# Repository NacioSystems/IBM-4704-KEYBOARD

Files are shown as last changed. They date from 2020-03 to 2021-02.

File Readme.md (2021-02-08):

# CONVERSOR IBM 4704 A USB:

## de NacioSystems:

Versión 1.0
Fecha 28/2/2020

Con este proyecto se explica la construcción de un interfaz para el teclado español 4704 de IBM de 62 teclas, para su utilización por USB en cualquier otro ordenador. 

---

### Introducción:

Paseado por el Rastro, en 1985, encontré un puesto que tenia varios teclados y terminales en venta. Tenía la pinta de que en una sucursal de banco habían cambiado de sistema y se habían deshecho de pantallas, terminales, impresoras y teclados. Había varios teclados, creo recordar que unos completos con caja, teclados de funciones y varios expandidos. 

Me llamó la atención, era la época de los *Conmmodore 64* y los *Spectrum*, esos teclados no estaban al alcance de cualquiera. En el Rastro nada es de fiar y no quería gastar mucho. Pregunté el precio y había uno económico por unas 100 pesetas. Se trataba de un teclado de terminal IBM 4704, que tenía la apariencia de estar estropeado, pues este en concreto era más barato y no disponía de caja externa.

Me gustó mucho su tacto, su sonido y decidí comprarlo. El teclado lo tuve de adorno en mi época de estudiante, lo guardé y muchos años después supe que estaba considerado uno de los mejores teclados, el *IMB Modelo F*, que por ser capacitivo superaba en prestaciones al más conocido Model M, tambien de IBM.

En 2020 decidí ponerlo en marcha y encontré mucha información en Internet. En concreto el proyecto de *[Soarer][1]*, quien destripó el hardware y el software del microprocesador Intel 8048, lo que a su vez permitió el desarrollo de otros proyectos de reconversión de este teclado en modelo USB, como es el caso del proyecto *[TMK][2]*.

Kishsaver Pruebas conexión

Este teclado es una matriz de 62 teclas, 8x8, en la que uno de los puntos de la matriz no es una tecla, el 63, es un código fijo que identifica el teclado, en mi caso 0xA3h. Para la lectura de la matriz se utiliza un controlador Intel 8048, aunque el teclado que yo tengo está marcado con un código diferente (8315), básicamente es un 8048, que se encarga de alimentar sucesivamenta cada una de las 8 filas, seleccionar cada una de las 8 columnas, mientras lee el valor 1 / 0 del pin 1, denominado TO. Interiormente el 8048 dispone de un microprocesador Intel de 8 bits, memoria RAM de 64 bytes y una ROM de 1kB, así como 3 puertos configurables de entrada salida tambien de 8 bits. La seleccion de las columnas es a través de un chip específico IBM (sensor capacitivo customizado IBM 9314) con entrada decimal (tres bits 0-7 que seleccionan la salida) y una salida por cada columna (8 salidas). Las entradas y salidas de Data, Clock y Buzzer se realizan a traves de puertas lógicas adicionales, que evitan cargar las salidas del 8048. Estas salidas están puestas en Pull-Up.

En concreto, para el modelo de 62 teclas, que los expertos llaman *Kishsaver*, realmente solo utiliza un puerto de 8 bits para el Strobe, la selección de filas, y mitad de otro puerto de 8 bits (bits 0, 1 y 2) para la selección de columnas. Un cuarto bit lo utiliza para la carga de los condensadores a través del IBM 9314 y un bit adicional para la lectura del Strobe de la tecla (que no existe) del código de teclado (ver imagen 8048).

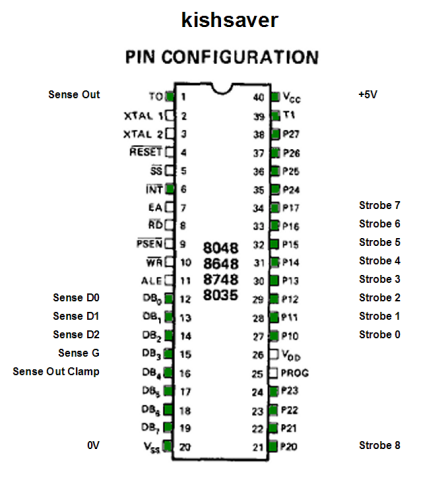
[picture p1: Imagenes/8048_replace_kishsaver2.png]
Intel8048 Intel 8048


La construcción es impresionante. Lleva dos planchas metálicas en las que encajan, en modo sandwich la placa de circuito impreso PCB y las teclas. La placa PCB está totalmente cubierta por una capa aislante por las dos caras, el soporte de la PCB hace de dieléctrico. Los contactos no son realmente contactos, son superficies que hacen de condensadores. El conjunto es sólido, el que yo tengo pesa 1.6Kg, pero he visto que el original con la caja de fundición pesa 2.8Kg. !Impresionante!

El teclado que yo tengo es un modelo de teclado español, con letra Ñ y otras teclas cambiadas de sitio respecto del teclado estándar, por lo menos la versión americana que documentó Soarer. A este teclado le encontré dos *Buckling springs*, los martillos de IBM rotos. Con estas características no resutla fácil la aplicación directa de un software estandar tipo *[Soarer][1]*, para aprovechar todas las capacidades de este teclado. 

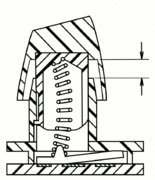
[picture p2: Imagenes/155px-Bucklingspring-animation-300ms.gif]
BucklingSpring Sistema IBM Buckling Spring


Es posible conseguir hardware adicional para reemplazar la placa controladora original por una más moderna, con puerto USB, pero los precios no son precisamente económicos. Hablamos de unos 41$ más gastos de envío (Ver proyecto TMK). 

Este modelo resultó tan bueno, que a través de micromecenazgo se creó un proyecto que diseñó, fabricó y vende este tipo de teclados, las piezas son iguales a las originales, y se respetó la calidad de los materiales. Esta calidad y la falta de economías de escala no permite que sea barato, los precios, para cualquiera de estos teclados andan por los 350$ más gastos de envío. Venden también piezas sueltas, cajas, martillos *buckling spring*, cápsulas de teclas, controladoras. Ver tienda en *[Model F Keyboards][9]*. Recomiendo ver el análisis en Youtube de *[Chyrosran22][10]*. En cualquier caso, los precios en el mercado de segunda mano para los Modelos F originales, superan estos precios.

Tomé la decisión de poner mi teclado a funcionar y me propuse buscar alternativas utilizando la información que *[Soarer][1]* ha hecho pública. La primera alternativa fue conectar un adaptador entre el bus del teclado y PC, con salida USB, basada en *Arduino Nano*. Si esto no funcionaba, en segundo lugar tenía previston reemplazar el controlador Intel 8048, instalando un zócalo de 40 pines, al igual que hizo *[Soarer][1]*, y reprogramando todo desde cero. Esta segunda alternativa era la que ofrecía más probabilidades desde mi punto de vista, ya que tenía el presentimiento de que el Intel 8048 no funcionaba.

Más tarde encontré, en el Github de *[iflowfor8hours][3]*, como hacer un conversor USB utilizando una placa Pro Micro, una placa similar a la placa Tennsy, la que utiliza Soarer, aunque con una configuración más limitada. Ambas placas vienen a ser un Arduino Leonardo reformado, en miniatura, con un microcontrolador _*ATmega32U4*_. Este controlador lleva incorporado un puerto USB nativo, lo que facilita enormemente la simulación de dispositivos *HID* en el ordenador.

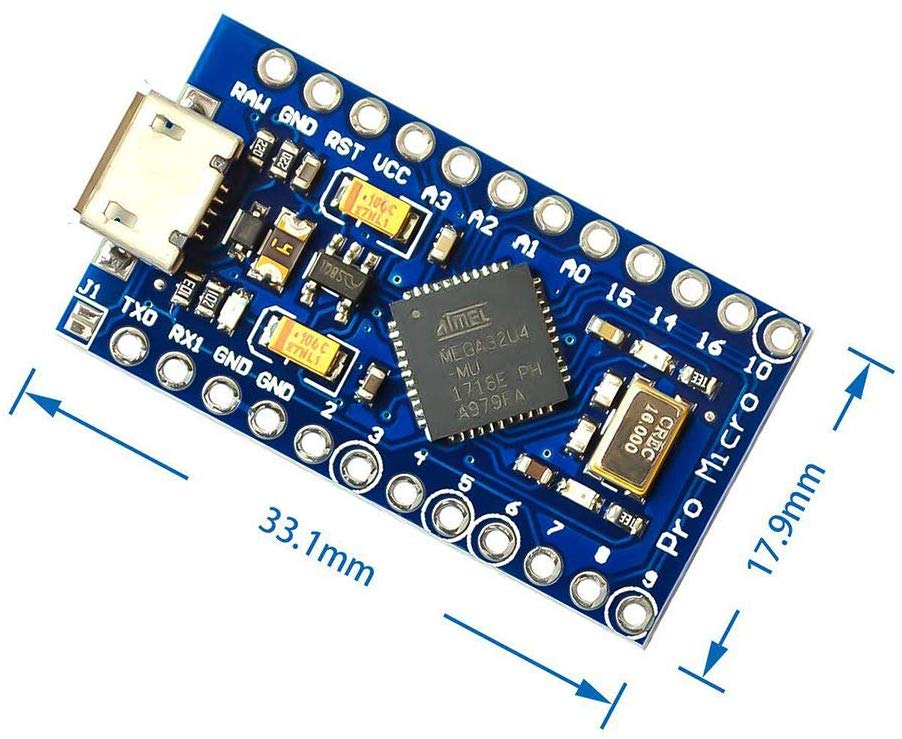
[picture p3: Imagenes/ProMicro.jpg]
ProMicro Pro Micro


El resultado no es inmediato, siguiendo las instrucciones de Soarer conseguí, despues de pelearme un poco con la información, salir del modo comando en el que se inicia el teclado y leer las teclas. Esto me permitió confirmar que el procesador IBM 8048 y el resto de la placa funcionan perfectamente despues de más de 35 años sin conectar.

Previamente a todo esto, desmonté el teclado, pues la suciedad acumulada en 35 años era considerable. Durante varios días estuve limpiando la placa, las cubiertas de acero, los soportes de las teclas y las teclas. Lo que más trabajo me dió fueron los soportes de las teclas ya que la cubierta de espuma que cubría las teclas, entre estas y la placa de acero superior, estaba desintegrada y pegada como con cola a los soportes de las teclas.

Una de las complicacines más difíciles fue el envío de comandos desde PC al teclado. Algunos comandos si los recibía sin problema, por ejemplo el comando RESET o SOFT_RESET, pero el resto de comandos como poner los *Break Codes* o los *Repit Codes* fué más complicado, parecía que los aceptaba y sin embarno no los ejecutaba. El problema estaba en que el teclado funciona siempre como maestro, manejando el reloj CLK, tanto en la lectura de códigos de escaneo como cuando se le envían datos de comandos, y yo intentaba enviarle los comandos controlando el reloj desde el PC. Una vez descubierto esto ya me puse a configurar un programa para que el IBM 4704 tenga un uso más funcional posible como teclado en español. Y funciona tan bien que es el teclado que utilizo:

Por cierto el teclado original tiene un beeper, un zumbador en base a electroimán, que suena en cada tecla pulsada. Creerme, el sonido de los martillos al pulsar la teclas hace innecesario dicho zumbador.

Una curiosidad interesante es que haciendo pruebas he descubierto que, con el teclado desarmado, sin teclas, con la placa base conectada, la simple pulsación con los dedos sobre las placas de los condensadores detecta cada una de las teclas. Es decir, los dedos pueden hacer de martillos capacitivos. Esto produce algunos errores de lectura de los Scan Codes, pero uno termina encontrando la forma de teclear sin teclas. Viendo esto voy a probar con otros tipos de materiales conductivos para ver si puedo reemplazar los dos martillos rotos.

### Materiales:
* Teclado IBM 4704 62 teclas, Kishsaver, modelo F
* Sparkfun Pro Micro

### Programa:

El programa está realizado con el IDE Arduino, para su programación directa a través de cable USB. En la carpeta software se puede ver el programa comentado. El pineado está explicado en los comentarios, sólo es necesario montar el cableado para la comunicación con el IMB 4704 y el puerto USB. La conexión con el PC abre un puerto HID Keyboard standar, para el envío de la información tecleada, pero por otra parte abre simultáneamente un puerto COM, en el que permite visualizar los códigos de escaneo del telcado, los códigos de conversión de teclas y los comandos enviados.

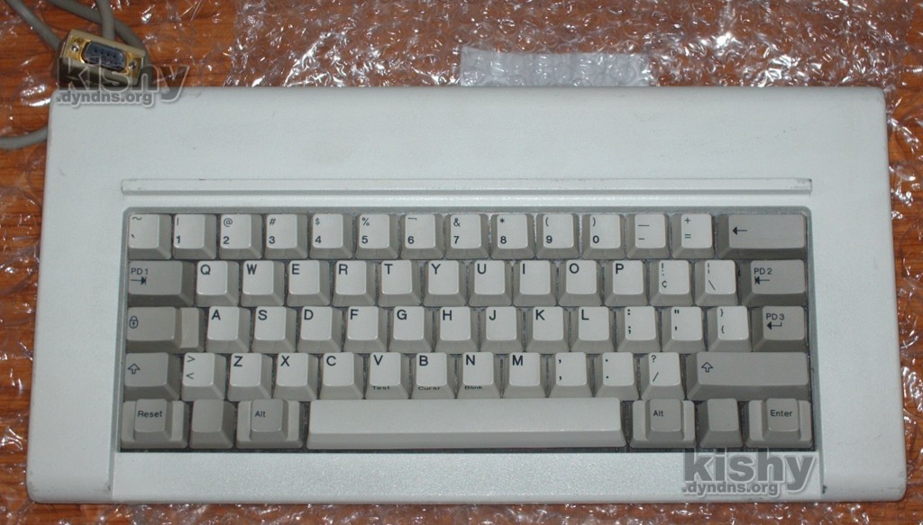
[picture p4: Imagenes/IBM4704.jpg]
IBM4704 IBM 4704 Kishsaver


### Construcción:

La construcción es en base es la plataforma **_Sparkfun Pro Micro_**, a la que se le han soldado conectores *duppond* hembra en los pines Vcc, GND, A3 y A4, los primeros para la alimentación de la placa con el procesador Intel 8048, los segundos para las fuciones de comunicación de IBM, CLK y DATA. 

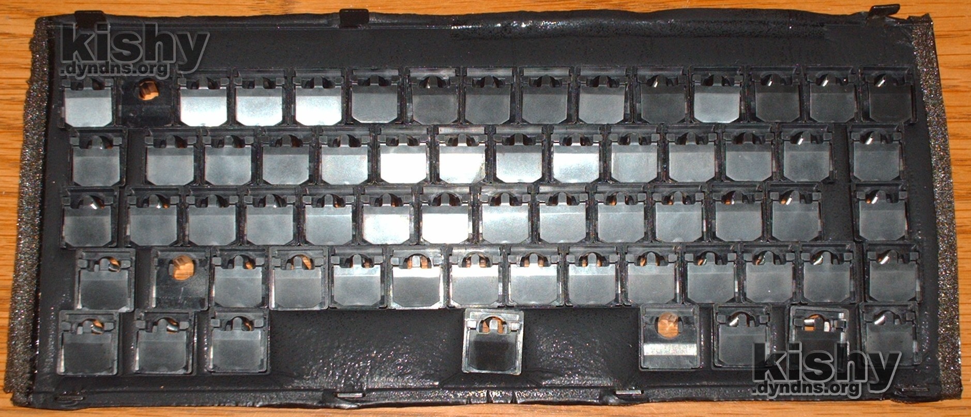
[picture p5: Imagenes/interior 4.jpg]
Martillos Interior, martillos


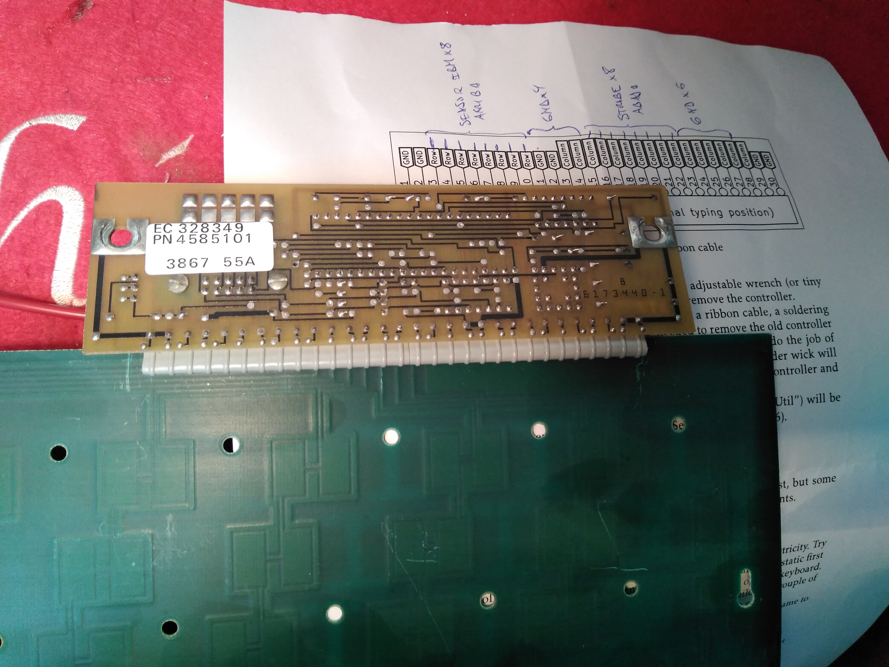
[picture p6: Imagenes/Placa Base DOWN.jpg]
Inferior Vista placa inferior


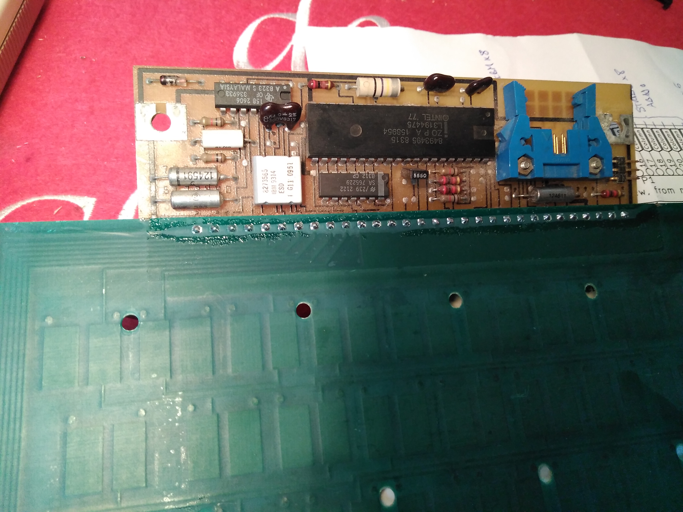
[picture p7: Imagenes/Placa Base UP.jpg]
Superior Vista placa superior


Por otra parte se diseñó una caja funcional, similar a la original de IBM, impresa en PLA, con una impresora 3D.

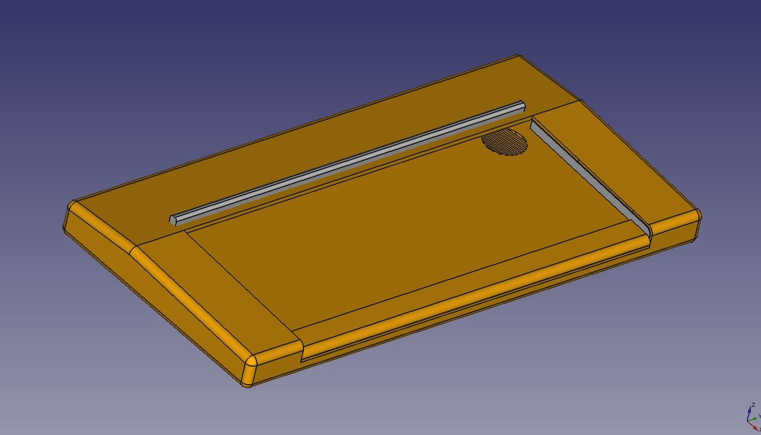
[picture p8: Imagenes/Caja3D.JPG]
Caja3D Modelo caja 3D


### Piezas impresas:

En la carpeta de piezas impresas, están los modelos Stl de la caja para el Kishsaver, imitando la caja original, modelo sacado a partir de la fotos ofrecidas por *[Kishy.ca][8]*.

Está tamibién el archivo FreeCad por si alguien quiere modificar dicha caja.

La impresora 3D que yo tengo tiene una superficie muy limitada, 200x200mm, lo que no me permite construir de una vez las dos partes, inferior y superior. Para poder imprimirlo, corté las piezas superior e inferior en dos partes dada una, derecha e izquierda, con unas dimensiones aceptables para el tamaño de la impresora. El material que utilicé es PLA de color dorado. 

Las mitades izquierda y derecha las pequé con cola y las uní con las levas inferior y superior para darle un refuerzo. La unión es con tornillos de métrica M3. Hay unas tuercas 4xM3 también embibidas en la parte superior, para sujetar con fuerza los tornillos. En la parte inferior tuve que meter un refuerzo, yo lo pegué con cola pero dejé espacio para tornillos, para hacerlo más rígido.

### Referencias:

* *[IBM 4700 Kishy.ca][5]*

* *[IBM 4704 to USB keyboard converter][6]*

* *[XT / AT / PS2 / Terminal to USB Converter with NKRO][7]*

* *[Sparkfun Pro Micro][4]*

### Autor:
**Ignacio Otero**

### Agradecimientos:

Muy agradecido tanto a *[Soarer][1]*, como *[iflowfor8hours][3]*, así como a *[http://kishy.ca][8]*, quienes me permitieron acceder a información esencial para conocer el funcionamiento de este teclado.

### Licencia:
Todos estos productos están liberados mediante Creative Commons Attribution-ShareAlike 4.0 International License.

[1]:https://deskthority.net/viewtopic.php?f=7&t=2510&start=

[2]:https://github.com/tmk/tmk_keyboard/tree/master/converter/ibm4704_usb

[3]:https://github.com/iflowfor8hours/6112884-pro-micro-controller

[4]:https://www.sparkfun.com/products/12640

[5]:http://kishy.ca/?p=648

[6]:https://github.com/tmk/tmk_keyboard/tree/master/converter/ibm4704_usb

[7]:https://geekhack.org/index.php?topic=17458.0

[8]:http://kishy.ca/?p=894

[9]:https://www.modelfkeyboards.com/

[10]:https://www.youtube.com/watch?v=nlbbBvS8wVY

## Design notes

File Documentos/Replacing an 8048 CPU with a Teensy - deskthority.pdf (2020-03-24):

Post Reply | First unread post • 15 posts • Page 1 of 1

# Replacing an 8048 CPU with a Teensy

Register | Login

mechanical keyboard authority

Soarer

07 Oct 2012, 04:58

My goal for this project is to get a DisplayWriter keyboard (beam spring) and the kishsaver (a Model F) converted to USB and usable. They don't have protocols that are usefully convertible, because they don't send release codes (or rather, they only send them for one or two keys).

Fully replacing the controller is an option - dfj has done so with a 122-key F, and it works well. But I fancied taking a different route, preferring to drive the IBM capacitive sensing chip by replacing the CPU. This means desoldering the original CPU, which naturally carries some risk of damage, but I've been lucky so far!

Some of the information here could of course be useful for replacing the 8048 in other, non-IBM, keyboards. The 8048 pins that might be used to scan a switch matrix are marked in green on this pinout:

Replacing an 8048 CPU with a Teensy - deskthority | https://deskthority.net/viewtopic.php?f=7&t=4019&start=
1 de 12 | 10/02/2020 10:03

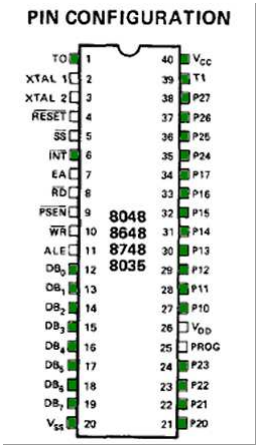
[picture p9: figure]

8048_replace.png (56.45 KiB) Viewed 3290 times
They are never all used just for reading the matrix. Some will be driving the external interface, and some may be driving LEDs. So a Teensy should have enough pins for any case, just! OTOH, something like a Teensy++ would make it easier to make a logical mapping between the 8048's three 8-bit ports, since the Teensy++ has four full ports (and/or might make physically mounting it in place easier, but more of that later).

Of the IBM controllers, there's a distinct similarity in pin use between the PC/XT and DisplayWriter (although of course there are big differences in pin use for the external interface):

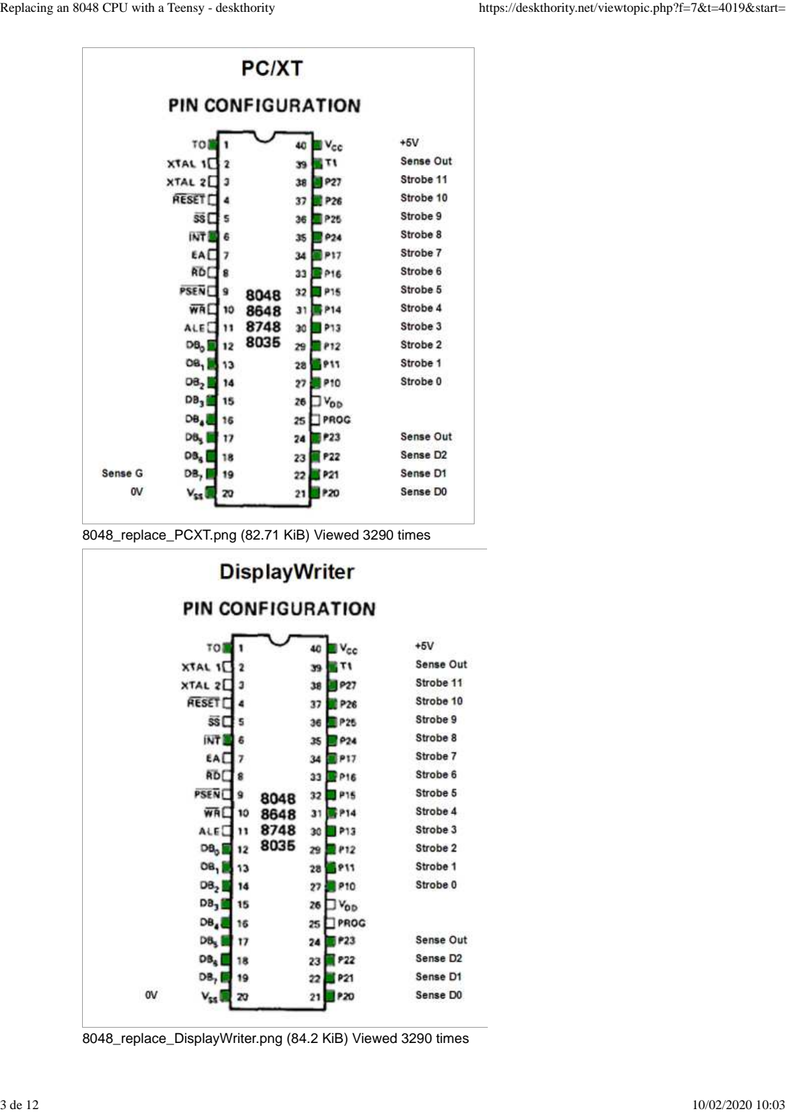
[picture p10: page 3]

8048_replace_PCXT.png (82.71 KiB) Viewed 3290 times

8048_replace_DisplayWriter.png (84.2 KiB) Viewed 3290 times

The AT uses a multiplexer for driving the strobe lines, so it doesn't use many pins at all. This same arrangement is also used in at least some of the 122-key terminal controllers:

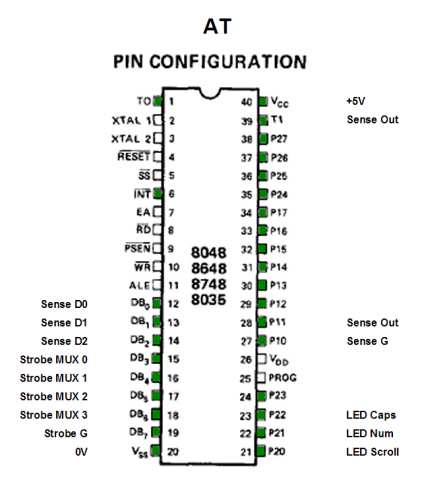
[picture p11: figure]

8048_replace_AT.png (78.69 KiB) Viewed 3290 times
And finally the kishsaver simply doesn't have many keys, so has fewer strobe lines:

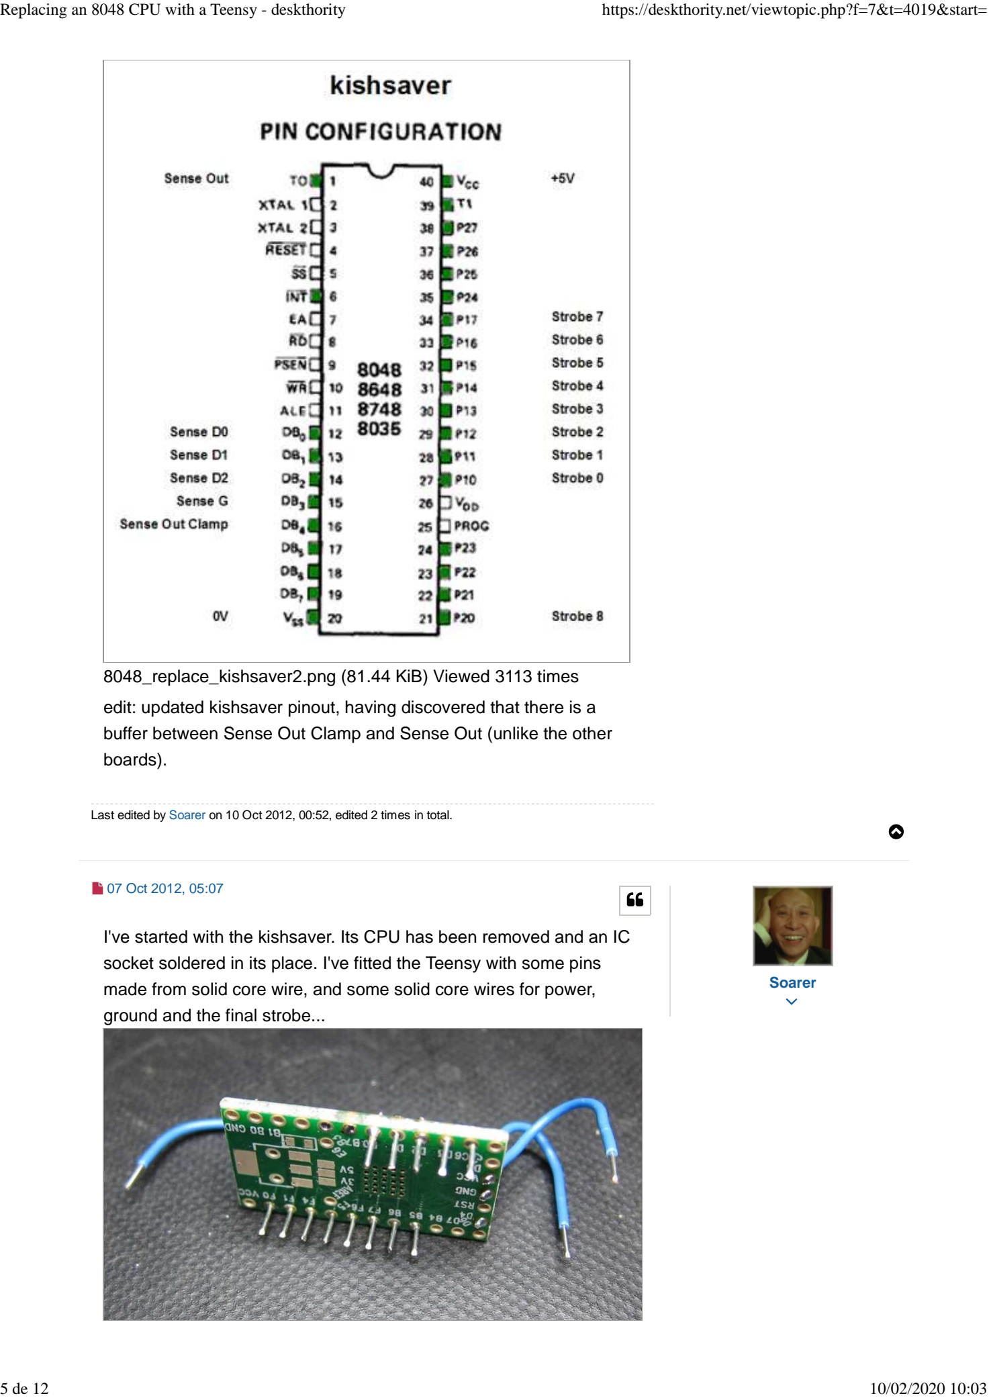
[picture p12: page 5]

8048_replace_kishsaver2.png (81.44 KiB) Viewed 3113 times edit: updated kishsaver pinout, having discovered that there is a buffer between Sense Out Clamp and Sense Out (unlike the other boards).

Last edited by Soarer on 10 Oct 2012, 00:52, edited 2 times in total.

Soarer

07 Oct 2012, 05:07

I've started with the kishsaver. Its CPU has been removed and an IC socket soldered in its place. I've fitted the Teensy with some pins made from solid core wire, and some solid core wires for power, ground and the final strobe...

kishsaver_teensy_pins.jpg (218.85 KiB) Viewed 3286 times

kishsaver_teensy_wires.jpg (263.67 KiB) Viewed 3286 times edit: updated this pic now that I've added a fourth wire to connect to the real Sense Out...

kishsaver_teensy2.jpg (258.07 KiB) Viewed 3108 times
Of course, I'll trim the wires a bit more when I'm happy with it!

I picked that position for the Teensy because it covers most of the used 8048 pins, and specifically it lines up PD0 to PD2 with Sense D0 to D2 - those three want to be changed together, so they at least need to be on the same Teensy port. The rest of connections will be read/written individually, so it doesn't matter if they're on different ports.

Last edited by Soarer on 10 Oct 2012, 00:48, edited 1 time in total.

07 Oct 2012, 07:02

To sniff the logic of the capacitive sensing chip, the AT is good

Soarer because of the multiplexer - less probes to attach!

A full scan of the entire matrix looks like this:

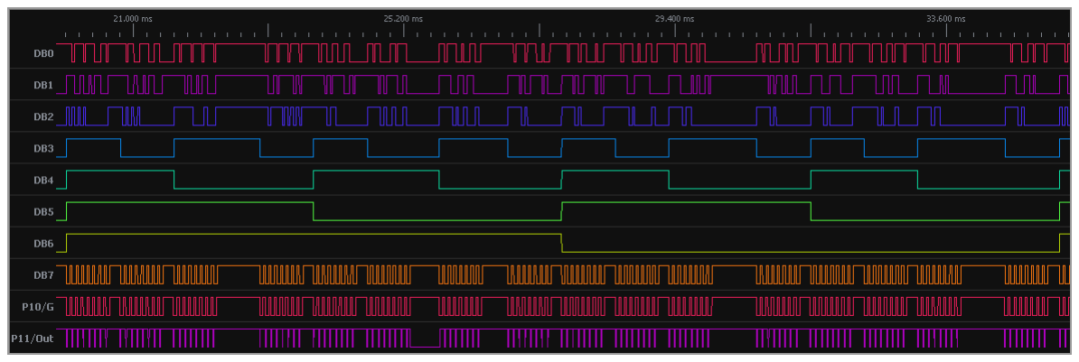
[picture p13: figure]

logic-sniff-at-f.png (6.17 KiB) Viewed 3272 times
Scanning the keys on a single column (or row, if you prefer), like this:

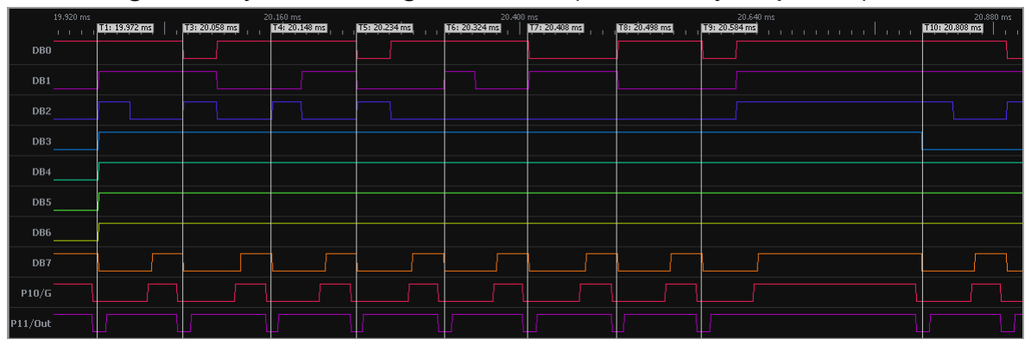
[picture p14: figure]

logic-sniff-at-f-2.png (6.83 KiB) Viewed 3272 times
Note that the Sense D0 to D2 lines (DB0 to DB2) serve a dual purpose - first, they select which key to read, and second, they set a sensitivity level (for which there is a table in the ROM).

When a key is pressed, the sense chip output (Out) goes low, when gated by the G line going high. The fifth key read in this scan is pressed:

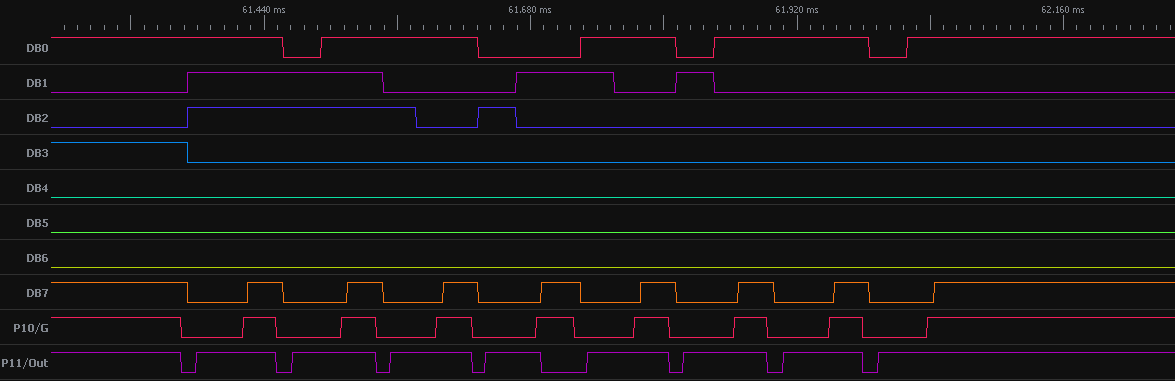
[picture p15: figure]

logic-sniff-at-f-f1-down.png (4.69 KiB) Viewed 3272 times
This subroutine from the AT's firmware reads a column of 8 keys:

CODE: SELECT ALL

X0251: clr | c | ; 0251 - 97 | .
mov | r0,#8 | ; 0252 - b8 08 8.
mov | r6,#0 | ; 0254 - be 00 >.
mov | a,r2 | ; 0256 - fa | z
dec | a | ; 0257 - 07 | .
anl | a,#0f8h | ; 0258 - 53 f8 Sx
mov | r7,a | ; 025a - af | /
X025b: dec | r2 | ; 025b - ca | J
anl | p1,#0fch | ; 025c - 99 fc .|
mov | a,r2 | ; 025e - fa | z
outl | bus,a | ; 025f - 02 | .
orl | p1,#2 | ; 0260 - 89 02 ..

rrc | a | ; 0262 - 67 | g
movp3 | a,@a | ; 0263 - e3 | c
jc | X0267 | ; 0264 - f6 67 vg
swap | a | ; 0266 - 47 | G
X0267: anl | a,#7 | ; 0267 - 53 07 S.
orl | a,r7 | ; 0269 - 4f | O
outl | bus,a | ; 026a - 02 | .
clr | c | ; 026b - 97 | .
nop | | ; 026c - 00 | .
nop | | ; 026d - 00 | .
nop | | ; 026e - 00 | .
orl | p1,#1 | ; 026f - 89 01 ..
orl | bus,#80h | ; 0271 - 88 80 ..

bhtooefr

07 Oct 2012, 12:40

Also, this method (but with different pinouts) will be useful for getting other beam springs going. (I'm looking over kbdbabel's 5251 schematic right now, at the AMI chip that I believe is the microcontroller. Unfortunately, the pinout doesn't match any kind of AMI microcontroller that I can find...)

Soarer

07 Oct 2012, 14:04

True... the CPU details aren't really as relevant as the peripherals around it, although it helps to cheat by looking at the code!

That 5251 uses the 4-channel version of the capsense chip - I would guess it's mostly driven in a similar fashion, but the 8-channel version doesn't have the U1 connection, so no idea what that's doing.

This thread could do with a more appropriate title. At first I was thinking of wiring a Teensy++ up to a DIL plug, so I could use it to replace the 8048 in any controller, but then I decided to just focus on one board first and make the simpler drop-in.

Soarer

07 Oct 2012, 14:24

For local reference, here are symbols for the capacitive sensing chips that akurz has used in the kbdbabel schematics.

The 4-channel version (5251 schematic):

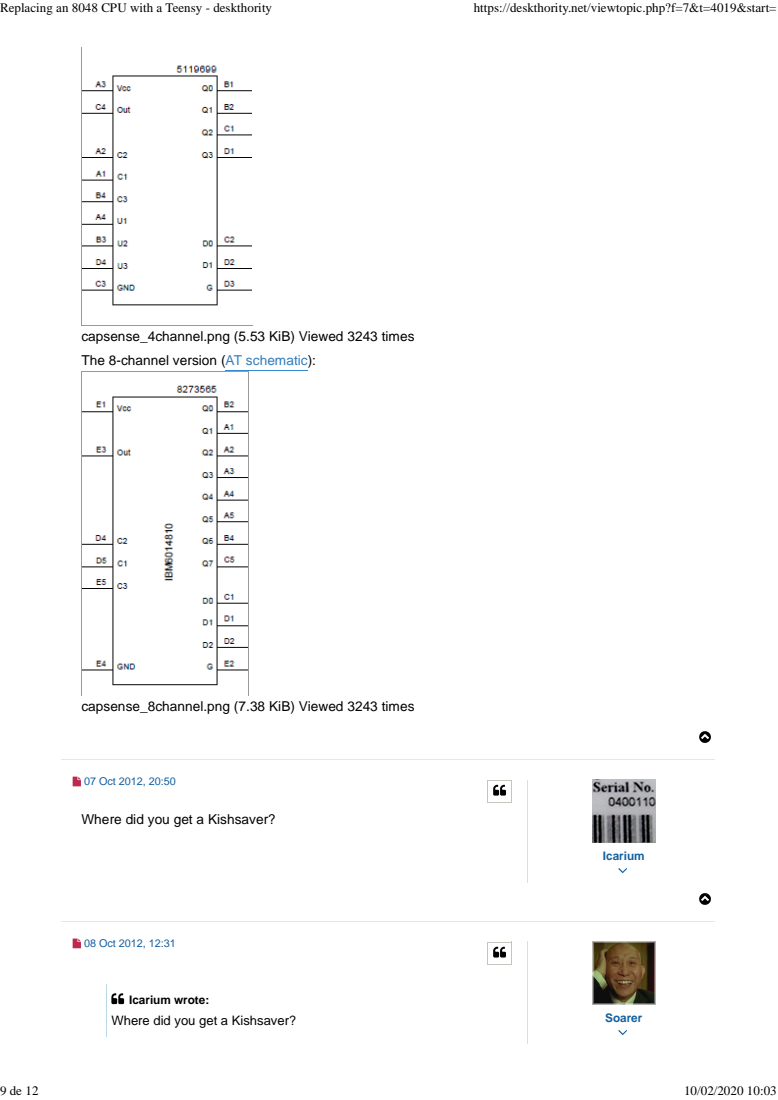
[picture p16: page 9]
Icarium; 07 Oct 2012, 20:50; Soarer; 08 Oct 2012, 12:31

capsense_4channel.png (5.53 KiB) Viewed 3243 times
The 8-channel version (AT schematic):

capsense_8channel.png (7.38 KiB) Viewed 3243 times

Where did you get a Kishsaver?

Icarium wrote:

Via another member. The source has dried up.

REVENGE 09 Oct 2012, 08:58

Interesting! Look forward to seeing what you manage to come up
with!

Soarer

10 Oct 2012, 01:14

Well I managed to get the matrix scan code basically working last night, but it will take a lot of trial and error to get it fully reliable!

I've updated a couple of the pics in the earlier posts because the kishsaver has a buffer connected to the pin it uses to clamp the Sense Out line low. None of the other controllers have a buffer there! Sense Out is the output from the capacitive sensing chip, and is normally connected to two pins on the CPU - one for reading it, and one for clamping it to ground. From the timing, this clamping could be an acknowledge back to the sensing chip - it appears to clear the previous output back to the unpressed state (high).

dorkvader

12 Oct 2012, 01:09

This is some very good and in-depth work! Would it be possible to adapt this project with some other components (like, reverse engineering the PCB) to make a teensy directly drive an IBM Model F, like Wcass's XTant project?

webwit
Wild Duck

12 Oct 2012, 02:26

Cool project. Making a beam spring keyboard work on a modern computer is a prize to be won! Also, I need you to convert my beam spring mini, so I finally have the Ultimate Keyboard.
Spoiler:

12 Oct 2012, 04:17

This thing is pissing me off today! I've made all the delays match the original ROM's timings, and it still doesn't read reliably when more

Soarer than a few keys on two sense lines are pressed at the same time. OTOH, it works perfectly up to having all 16 keys on two strobe lines
pressed. Also, I'm having to set the lowest sensitivity (7) when the
original ROM happily uses 2 (this one self calibrates at startup),
otherwise I get random keypresses registered. I must be missing something.

dorkvader wrote:
This is some very good and in-depth work! Would it be possible to adapt this project with some other components (like, reverse engineering the PCB) to make a teensy directly drive an IBM Model F, like Wcass's XTant project?

It's the mysterious square silver capacitive sensing chip that's hard to replicate, if trying to completely replace the controller PCB.

webwit wrote:
Cool project. Making a beam spring keyboard work on a modern computer is a prize to be won! Also, I need you to convert my beam spring mini, so I finally have the Ultimate Keyboard.

So... do we know which sense chip that has? I haven't got anything with the 4-channel version, yet. Got any pics of the controller PCB?

wcass

12 Oct 2012, 06:11

Soarer wrote:

dorkvader wrote:
This is some very good and in-depth work! Would it be possible to adapt this project with some other components (like, reverse engineering the PCB) to make a teensy directly drive an IBM Model F, like Wcass's XTant project?

It's the mysterious square silver capacitive sensing chip that's hard to replicate, if trying to completely replace the controller PCB.

would it help to have a few XT controllers? i would be happy to ship them to someone with the skills to use them.

12 Oct 2012, 21:22

wcass wrote:

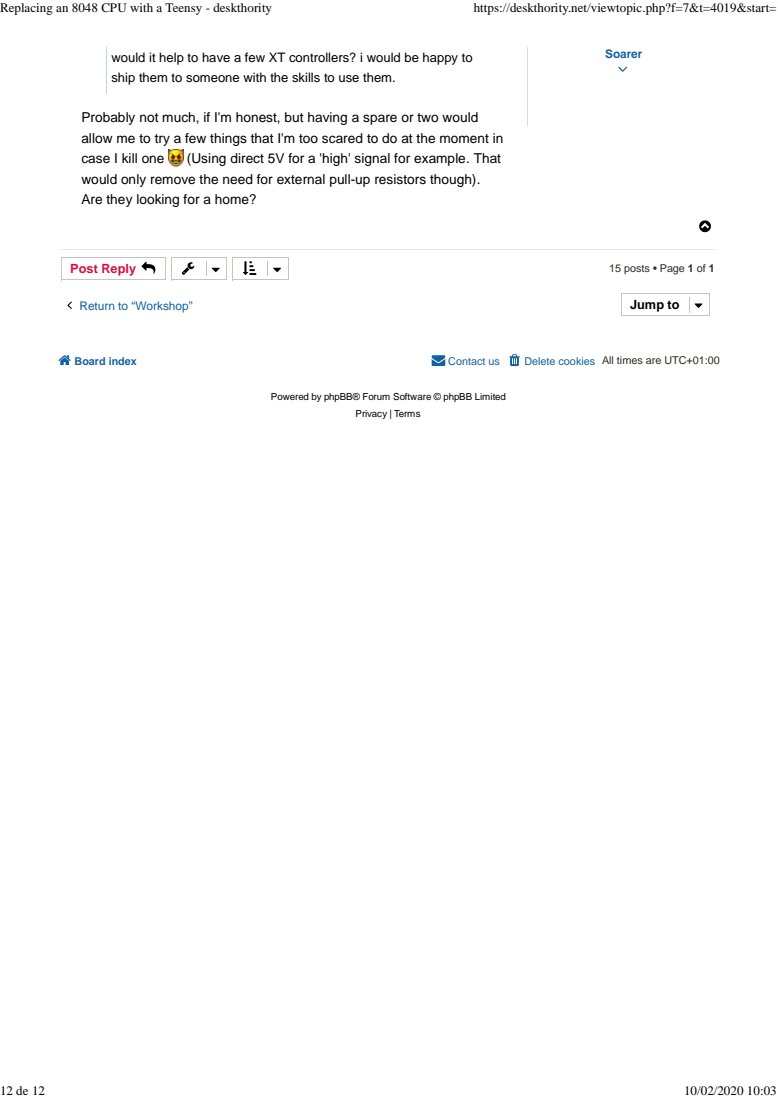
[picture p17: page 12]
Post Reply; 15 posts • Page 1 of 1; Board index; Contact us; Delete cookies All times are UTC+01:00; Privacy | Terms; would it help to have a few XT controllers? i would; Soarer be happy to; case I kill one; (Using direct 5V for a 'high' signal for example. That; Jump to

ship them to someone with the skills to use them.

Probably not much, if I'm honest, but having a spare or two would
allow me to try a few things that I'm too scared to do at the moment in
would only remove the need for external pull-up resistors though).
Are they looking for a home?

Return to “Workshop”

Powered by phpBB® Forum Software © phpBB Limited

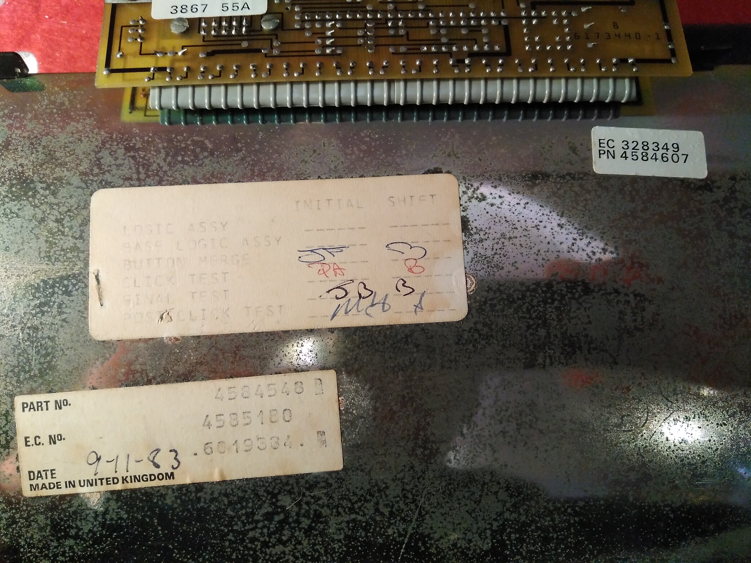
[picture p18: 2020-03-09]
Imagenes/Detalle Etiquetas.jpg

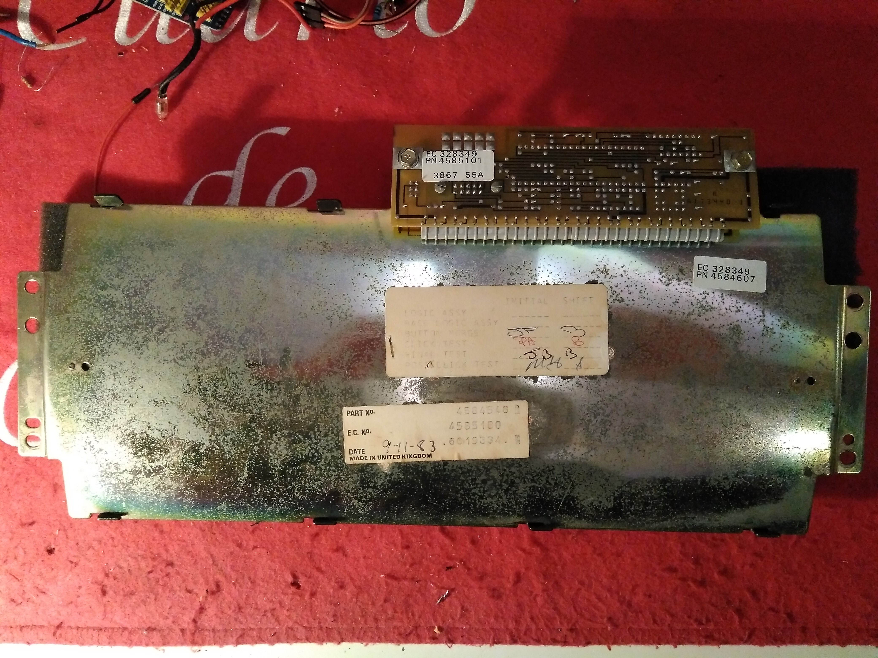
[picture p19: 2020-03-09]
Imagenes/Teclado Vista Inferior.jpg

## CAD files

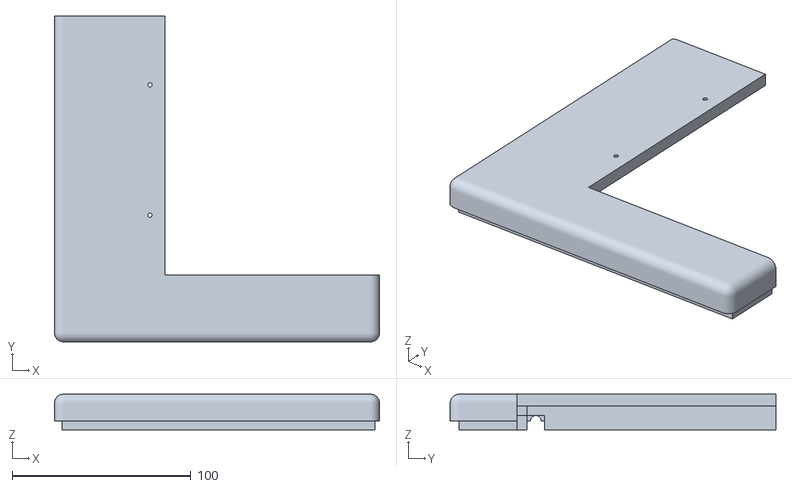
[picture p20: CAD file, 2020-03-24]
Caja 3D/Parte Superior Izquierda.stl
182.1 x 182.5 x 20.1

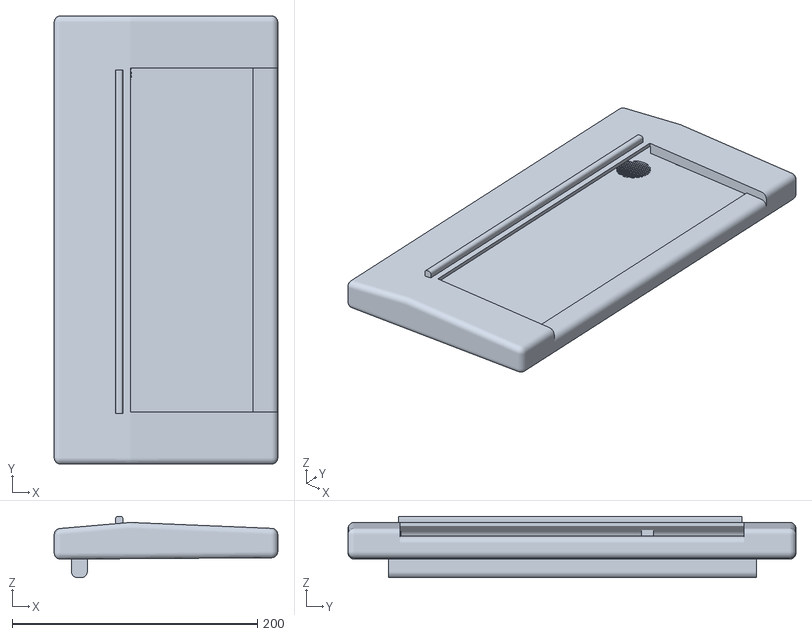
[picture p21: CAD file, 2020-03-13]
Piezas Impresas/Caja IBM 4704 B.stl
182.2 x 365.0 x 50.0

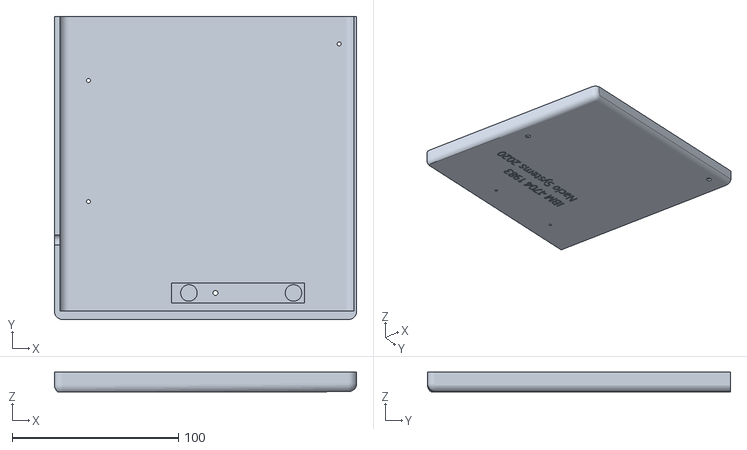
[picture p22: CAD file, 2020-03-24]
Caja 3D/Parte Inferior Izquierda.stl
182.0 x 182.5 x 12.0

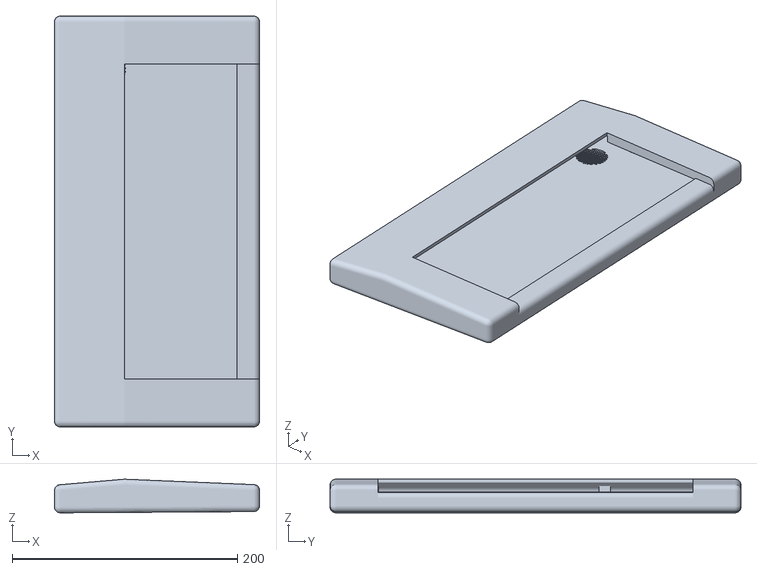
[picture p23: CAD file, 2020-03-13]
Piezas Impresas/Caja IBM 4704.stl
182.2 x 365.0 x 29.9

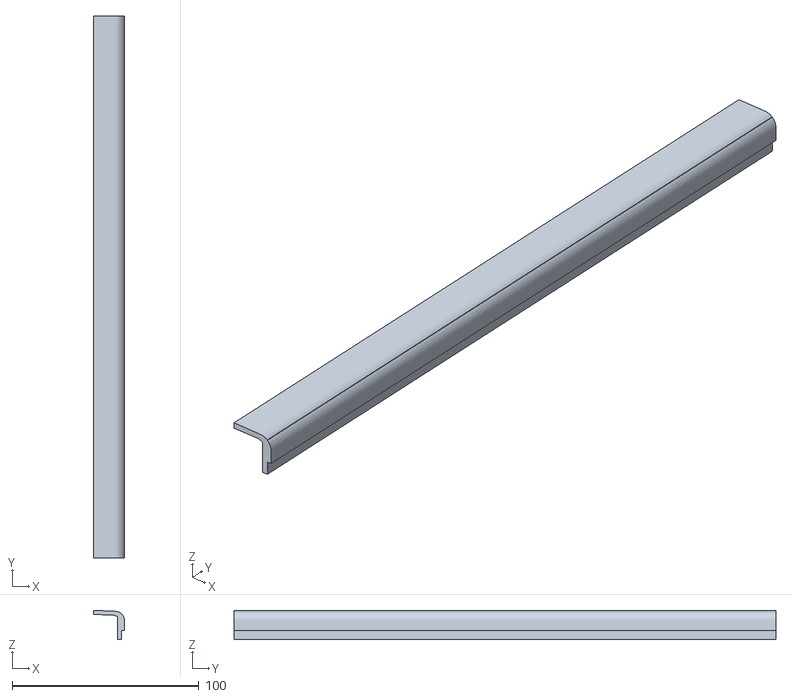
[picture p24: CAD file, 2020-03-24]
Caja 3D/Borde Manos.stl
16.6 x 290.0 x 15.7

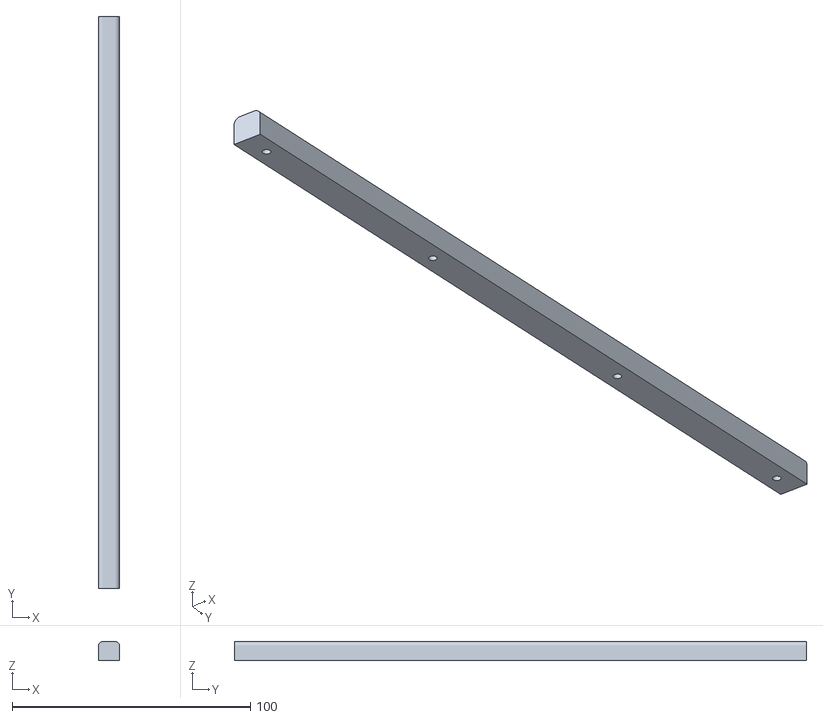
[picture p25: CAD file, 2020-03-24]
Caja 3D/Centro Barra Superior.stl
9.00 x 240.0 x 8.00

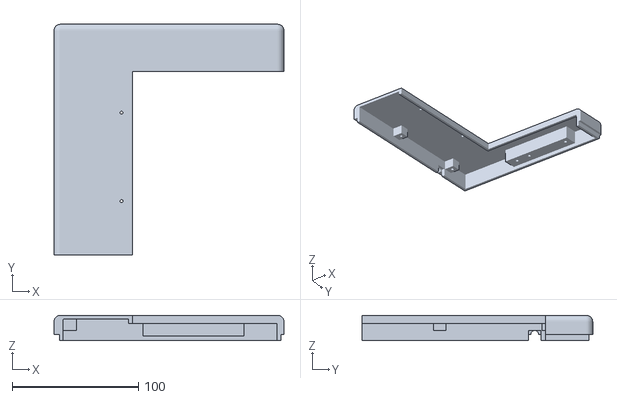
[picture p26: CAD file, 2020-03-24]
Caja 3D/Parte Superior Derecha.stl
182.1 x 182.5 x 20.1

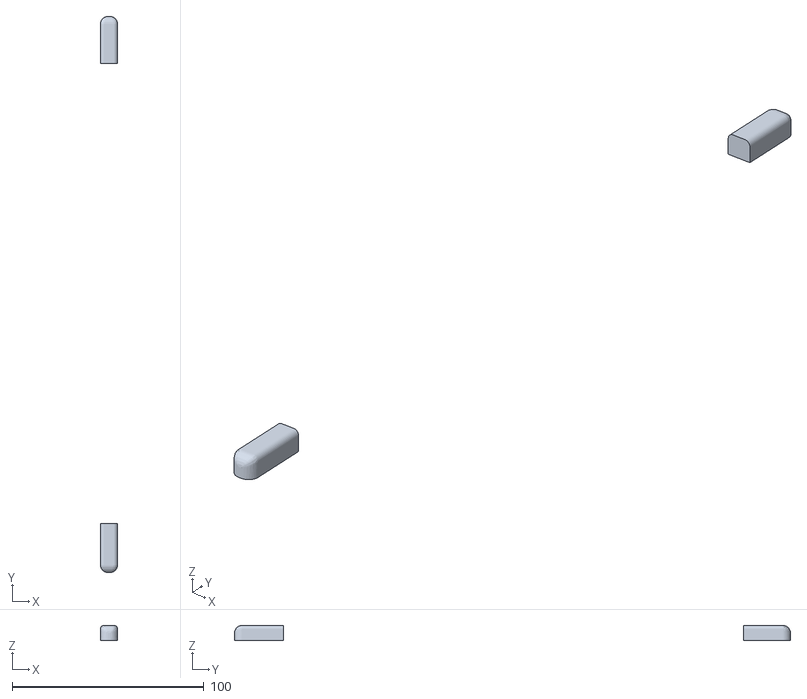
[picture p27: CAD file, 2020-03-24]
Caja 3D/Extremos Barra Superior.stl
9.00 x 290.0 x 8.00

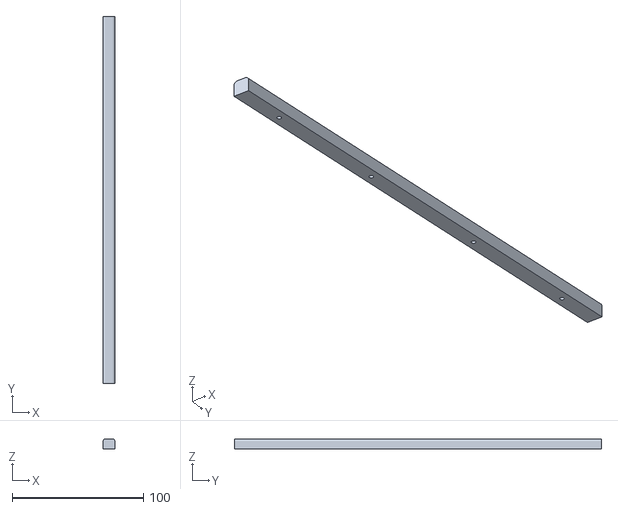
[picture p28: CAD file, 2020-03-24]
Caja 3D/Borde Superior.stl
9.00 x 280.0 x 8.00

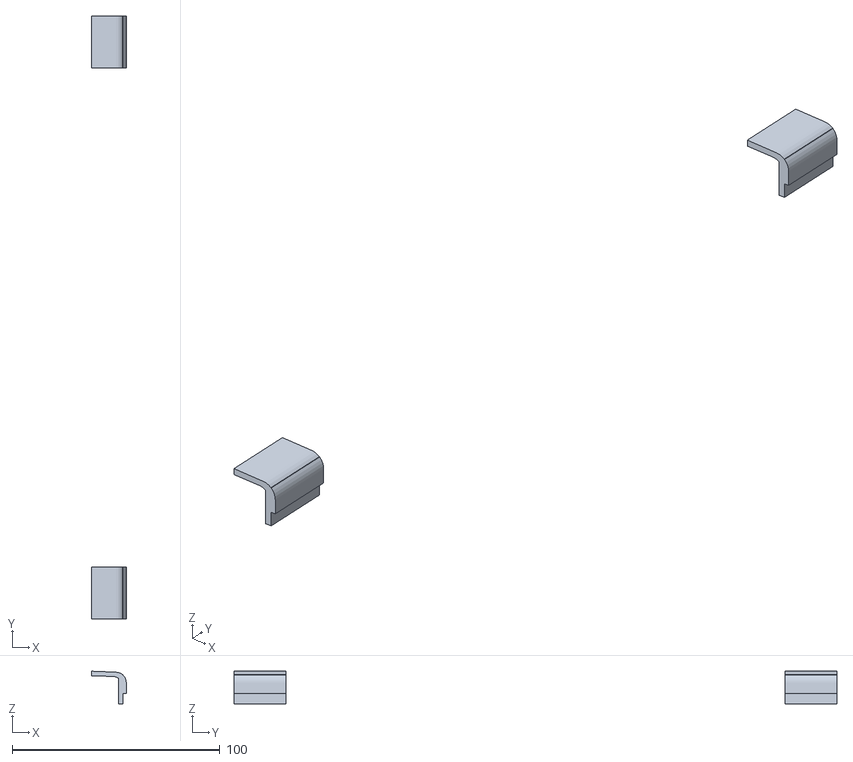
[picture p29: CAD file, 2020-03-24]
Caja 3D/Extremos Reposa Manos.stl
16.6 x 290.0 x 15.7

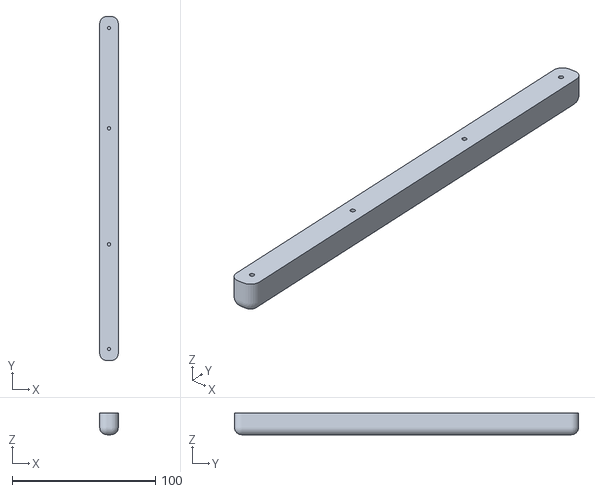
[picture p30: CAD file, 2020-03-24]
Caja 3D/Leva Inferior.stl
13.0 x 240.0 x 15.0

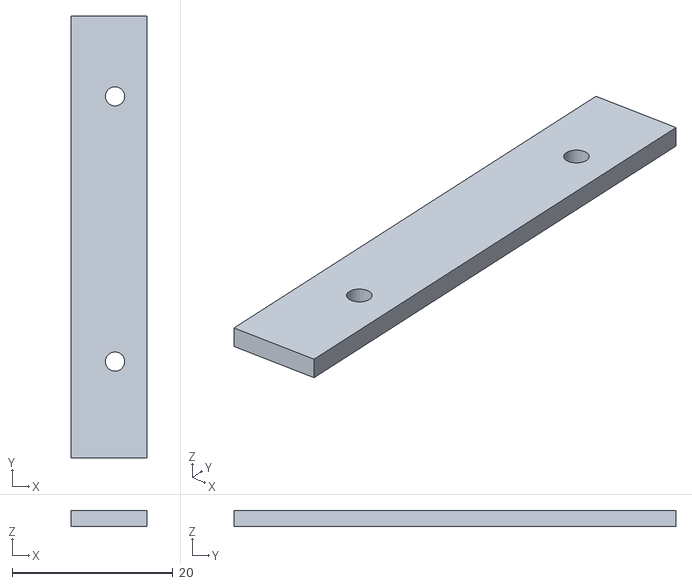
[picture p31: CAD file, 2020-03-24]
Caja 3D/Refuerzo Inferior.stl
9.50 x 55.0 x 2.00

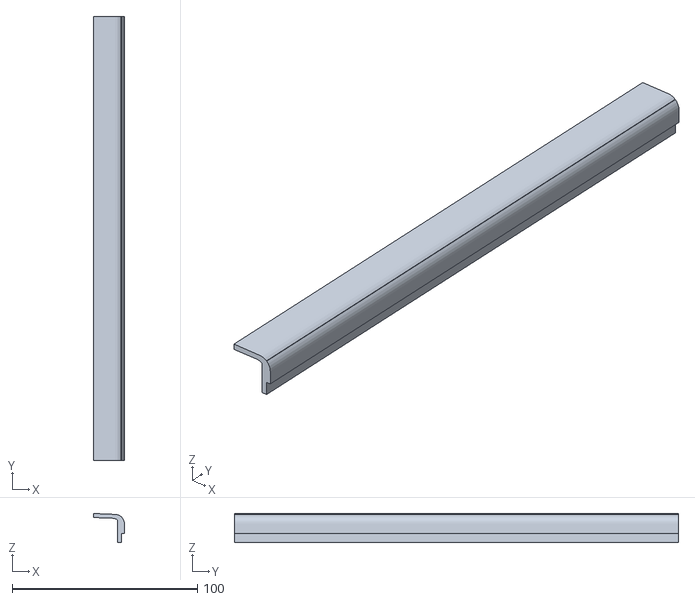
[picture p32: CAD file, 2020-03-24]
Caja 3D/Centro Reposa Manos.stl
16.6 x 240.0 x 15.7

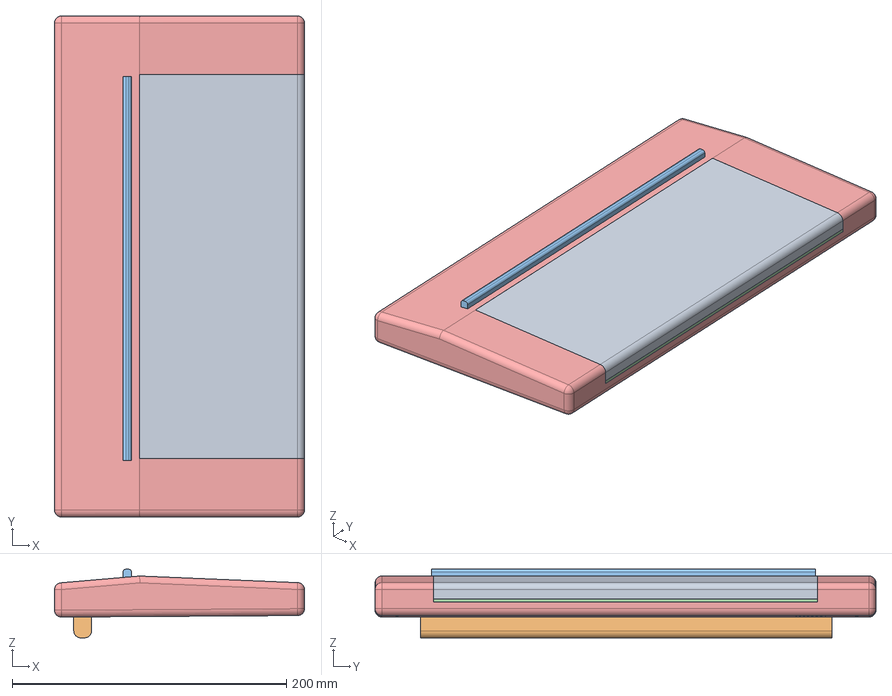
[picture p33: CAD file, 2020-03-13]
Caja 3D/Caja IBM Model F 2.FCStd
182.2 x 365.0 x 50.0 mm
Rebajes cabezas tornillos
Refuerzos cableza
Taladros cabeza
Pared lateral 1
Pared lateral 2

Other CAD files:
Caja 3D/Parte Inferior Derecha.stl

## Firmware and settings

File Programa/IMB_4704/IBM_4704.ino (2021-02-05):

// Realizado por Ignacio Otero
// Marzo de 2020, en pleno confinamiento por la Crisis del Coronavirus
// Modificado en enero de 2021, incluye control de los tiempos de las comunicaciones. Si se sobre pasan 
// da error y aborta la comunicación.

// Lectura de teclado IBM modelo F
// Referencias en Github:
//      https://github.com/NacioSystems/IBM-4704-KEYBOARD

// Preparado para funcionar en un Arduino Pro Micro
// Utilizamos A3 para lectura del reloj
//          y A4 para lectura y escritura de datos

// Queda pendiente reconfigurar todo para funcionar con 
// interrupciones.

#include "Configuracion.h"
#include "Keyboard.h" // Es una librería adaptada de Keyboard.h para el 4703 
// El modivo de modificar esta libreria es que la librería Keyboard.h corta los códigos de las teclas a 7 bits
// y para enviar la tecla '<', el código es el 0xE2. Con el código 0x60 lo que reconoce en español es la ';'
// En caso de reprogramar marcar la línea anterior y desmarcar la siguiente.

// Variables generales
volatile unsigned long Ttotal, Tabajo, Talto;
volatile boolean HayDato=false;
volatile char Dato=0x00;
uint8_t ValorTecla=0;
uint8_t Error=00;
int contador=0;

boolean SHIFT = false;
boolean ALT=false;
boolean CONTROL=false;
boolean BREAK_CODE=false;
boolean FUNCION_E=false;


// Creo un ana matriz de 8x8, 64 caracteres (0x40 en Hexadecimal,8 de propina), para convertir los códidos de 
// escanéo del teclado en códigos ASCII entendibles por el PC.
// Son las teclas básicas.
// Estos códigos se cambian si son caractéres raros, que no se corresponden con su posición habitual
// Ejemplo: '\', 'º','ª','@','<','>'
char CodTeclado[0x48] = {   
    // 00         01    02    03    04         05    06    07         
       KEY_ESC,   'i',  'o',  'p',  KEY_TAB,   'q',  'w',  ' ',
       
    // 08    09    0A    0B    0C               0D     0E               0F 
       '7',  '8',  '9',  ' '  ,KEY_BACKSPACE,   0x27,  KEY_BACKSPACE,   '0',
       
    // 10    11    12    13    14    15    16    17
       '4',  '5',  '6',  'e',  'r',  't',  'y',  'u',
       
    // 18    19    1A    1B`       1C+    1D            1E    1F'
       '1',  '2',  '3',  0x5B,  0x5D,  KEY_DELETE,   ' ',  0x2D,  // KEY_ACENTO2 1B

    // 20               21a    22    23    24    25    26    27
       KEY_CAPS_LOCK,   0X61,  's',  'd',  'f',  'g',  'h',  'j',

    // 28    29    2Añ    2B'    2Cç    2D            2E    2F
       'k',  'l',  0x3B,  0x27,  0xBF,  KEY_RETURN,   ' ',  KEY_RIGHT_ALT, // KEY_CEDILLA 2C

    // 30                31               32    33    34    35    36b    37
       KEY_LEFT_SHIFT,   KEY_LEFT_CTRL,   'z',  'x',  'c',  'v',  'b',  'n',

    // 38    39    3A    3B/    3C                3D                 3E<         3F
       'm',  ','  ,'.',  0X2F,  KEY_RIGHT_SHIFT,  KEY_RIGHT_SHIFT,   60,  KEY_LEFT_ALT,

    // 40    41               42              43    44    45    46    47
       ' ',  KEY_LEFT_GUI,   KEY_RIGHT_GUI,   ' ',  ' ',  ' ',  ' ',  ' '    
};


void setup() {
  Keyboard.begin();
  Serial.begin(57600); // Utilizaremos el puerto serie para salida  
  
  // Esperamos que arranque el teclado y envíe un 0xA3h
  delay(1000); // 1 segudo será suficiente

  // Ponemos un menú por el puerto serie explicando las teclas más importantes
  InformacionSerie();
  // Reiniciamos teclado
  InicioTeclado();
  
  delay(1000);
}

void loop() {
// Durante el loop, leemos si hay algún dato en el teclado
// En el caso de que no tengamos nada el resultdo es 0xFF
// En caso positivo, descodificamos la transmision y la pasamos
// por USB con la librería Keyboard.

// leemos teclado
ValorTecla=LeerTeclado();

// Inhabilitamos KB para que no nos envíe nada por ahora
// En la función LeerTeclado ya se habilita
inhabilitaKB();
  
if (ValorTecla!=0xFF) {
      // Hay valor, imprimirmos el valor
      Serial.print(" Codigo tecla: 0x");      //
      Serial.print(ValorTecla, HEX);
      Serial.print(" --> Codigo enviado: 0x");
      Serial.println((uint8_t) CodTeclado[ValorTecla],HEX);
      //Serial.print(" Tecla: ");

      // Si es ESCAPE levantamos los modificadores y teclas pulsadas
      if(ValorTecla==0x00) {
           if(CONTROL&ALT) { // Es por si es el backslash, que también está en el acento francés
                  Keyboard.press(KEY_LEFT_CTRL);
                  Keyboard.press(KEY_LEFT_ALT);
                  Keyboard.press(0x60);       // Tecla 'º','ª' y '\' en el teclado normal
                  delay(50);
                  Keyboard.releaseAll();
                  }
           else {
                 SHIFT = false;
                 ALT=false;
                 CONTROL=false;
                 BREAK_CODE=false;
                 FUNCION_E=false;
                 Keyboard.releaseAll();
                 }
           }
      // Otros valores, teclas modificadoras y otras teclas cambiadas:
      // Paréntesis y corchetes {[]}, @
      switch (ValorTecla) {
          // EN FUNCIÓN DE LAS TECLAS HACEMOS...
          // TECLAS MODIFICADORES Y TECLAS RARAS
          //    
          case 0x1D:  // RESETEO, FUNCION_E Y SUPRIMIR (PD2 <-)
              if(FUNCION_E) {
                InformacionSerie();
                InicioTeclado();
                delay(1000);    
                }
                else { // Es un suprimir normal
                   Keyboard.press(CodTeclado[ValorTecla]);
                   }
                // Liberamos la tecla suprimir en el PC tanto si es suprimir como si reseteo
                delay(50);
                Keyboard.release(CodTeclado[ValorTecla]);
              break;
          case 0x30: // LIBERA SHIFT
              SHIFT=false; 
              Keyboard.release(CodTeclado[ValorTecla]);
              break;
          case 0xB0: // SHIFT
              SHIFT=true;
              Keyboard.press(CodTeclado[0x30]);
              break;
          case 0x3F: // ALT. ALT tiene el mismo código en los dos lados
              ALT=false;
              Keyboard.release(CodTeclado[ValorTecla]);
              break;
          case 0xBF: // ALT
              ALT=true;
              Keyboard.press(CodTeclado[0x3F]);
              break;
          case 0x31: // CONTROL
              CONTROL=false;
              Keyboard.release(CodTeclado[ValorTecla]);
              break;
          case 0xB1: // CONTROL
              CONTROL=true;
              Keyboard.press(CodTeclado[0x31]);
              break;
         case 0xC1: // FUNCIONES ESPECIALES, MENÚ INICIO
              FUNCION_E=true;
              //Keyboard.press(CodTeclado[0x41]); // En caso de que se utilizara para menú de Windows
              break; 
         case 0x41: // FUNCIONES ESPECIALES
              FUNCION_E =false;
              //Keyboard.release(CodTeclado[0x41]); // En caso de que se utilizara para menú de Windows
              break;
              
         case 0x1A: // La @ está en el 3 no en el 2
              if(SHIFT) {
                   Keyboard.press(KEY_LEFT_CTRL);
                   Keyboard.press(KEY_LEFT_ALT);
                   Keyboard.press(0x32); // Tecla 2 que es arroba" 
                   }
              else Keyboard.press(CodTeclado[ValorTecla]); // Tecla 3
              delay(50);
              Keyboard.releaseAll();
              //Keyboard.press(KEY_LEFT_SHIFT); // Estábamos con Shift lo dejamos arriba
              break;
         case 0x0D: // { Cambiar por Control + alt + tecla acento
              if(!SHIFT) { // Abre corchete {
                      Keyboard.press(KEY_LEFT_CTRL);
                      Keyboard.press(KEY_LEFT_ALT);
                      Keyboard.press(0x27);
                      }
              else { // [ Abre corchete grande
                      Keyboard.press(KEY_LEFT_CTRL);
                      Keyboard.press(KEY_LEFT_ALT);
                      Keyboard.press(0x5B);
              }
              delay(50);
              Keyboard.releaseAll();
              break;
          case 0x2C: // } Control + alt + tecla CEDILLLA
              if(FUNCION_E) { // Cierra corchete }
                     Keyboard.press(0x5C);
                     Keyboard.release(0x5C);
              }
              else
              if(!SHIFT) { // Cierra corchete 1 ]
                      Keyboard.press(KEY_LEFT_CTRL);
                      Keyboard.press(KEY_LEFT_ALT);
                      Keyboard.press(0xBA);
                      Keyboard.releaseAll();
                      }
              else { // ]
                      Keyboard.press(KEY_LEFT_CTRL);
                      Keyboard.press(KEY_LEFT_ALT);
                      Keyboard.press(0x5D);
                      Keyboard.releaseAll();
              }
              break;
              
          default:
              if(!FUNCION_E) {  // TELCAS NORMALES
                  Keyboard.press(CodTeclado[ValorTecla]);
                  delay(50);
                  Keyboard.release(CodTeclado[ValorTecla]);
              }
        // TECLAS DE FUNCIÓN ESPECIAL
              else { // TECLAS ESPECIALES
                //MOVIMIENTO CURSOR
                        switch (ValorTecla) {
                           case 0x35: // V Izquierda
                              Keyboard.press(KEY_LEFT_ARROW);
                              break;

                           case 0x36: // B Abajo
                              Keyboard.press(KEY_DOWN_ARROW);
                              break;

                           case 0x37: // N Derecha
                              Keyboard.press(KEY_RIGHT_ARROW);
                              break;

                           case 0x25:  // G Arriba
                              Keyboard.press(KEY_UP_ARROW);
                              break;
                              
                // TECLAS INCICIO, AVANCE PÁG Y RET. PÁG.
                           case 0x01:  // I Incio 'i'
                              Keyboard.press(KEY_HOME);
                              break;
                           case 0x24:  // F Fin 'f'
                              Keyboard.press(KEY_END);
                              break;
                           case 0x21:  // A Av Pag 'a'
                              Keyboard.press(KEY_PAGE_DOWN);
                              break;
                           case 0x14:  // R Re Pag 'r'
                              Keyboard.press(KEY_PAGE_UP);
                              break;
                              
                // IMPRIMIR PANTALLA
                           case 0x03:  // p Imprimir Pantalla
                              //Keyboard.press(0x2C); // Desconozco el codigo
                              break;
                        
                // TECLAS FUNCIÓN O CARACTERES MAYÚSCULAS NUMÉRICOS
                           case 0x18: // F1 o ¡
                              if(SHIFT) {
                                 Keyboard.release(KEY_LEFT_SHIFT); // Quitemos el SHIFT
                                 Keyboard.press(61);// abre admiración ¡
                              }
                              else Keyboard.press(KEY_F1); 
                              break;
                           case 0x19: // F2
                              Keyboard.press(KEY_F2);
                              break;
                           case 0x1A: // F3
                              Keyboard.press(KEY_F3);
                              break;
                           case 0x10: // F4
                              Keyboard.press(KEY_F4);
                              break;
                           case 0x11: // F5
                              Keyboard.press(KEY_F5);
                              break;
                           case 0x12: // F6
                              Keyboard.press(KEY_F6);
                              break;
                           case 0x08: // F7
                              Keyboard.press(KEY_F7);
                              break;
                           case 0x09: // F8
                              Keyboard.press(KEY_F8);
                              break;
                           case 0x0A: // F9
                              Keyboard.press(KEY_F9);
                              break;
                           case 0x0F: // F10
                              Keyboard.press(KEY_F10);
                              break;
                           case 0x1F: // F11 o ¿
                              if(SHIFT) {
                                Keyboard.press(KEY_LEFT_SHIFT);
                                Keyboard.press(61);// abre pregunta
                                }
                              else Keyboard.press(KEY_F11);
                              break;
                           case 0x0D: // F12
                              Keyboard.press(KEY_F12);
                              break;

                           // Otras teclas raras ºª
                           case 0x02: // Pulsando la 'O' con función
                              // Si es con mayúsculas es la 'ª'
                              // Minúsculas es la 'º'
                              Keyboard.press(0x60);
                              break;
                              
                           case 0x1B: // '\' Backslash
                              Keyboard.press(KEY_LEFT_CTRL);
                              Keyboard.press(KEY_LEFT_ALT);
                              Keyboard.press(0x60);       //
                              Keyboard.releaseAll();
                              break;
                          }
               
               Keyboard.releaseAll(); // Soltamos todas las teclas
               // Si tenemos pulsado el SHIFT lo volvemos a poner
               if(SHIFT) Keyboard.press(KEY_LEFT_SHIFT);
               delay(50); 
              } // Fin de parte de telclas especiales
          } // Fin del bulcle switch valor tecla

       
      } // Fin del bucle en el que hay dato
} // FIN DE LOOP

// ENVIAR COMANDO
void EnviarComando(uint8_t Comando) {
/*Host to Keyboard
----------------
No lo dice en ninguna parte, pero el Keyboard hace siempre de Master, controlando el CLK.
El PC sólo lee el CLK del teclado y lo pone a LOW para herle saber que le va a envar datos;
liberando después el CLK para que lo controle el KB.

Data bits are LSB first and Pairty is odd. Clock has around 60us high and 30us low part.

            ____        __   __   __   __   __   __   __   __   __   ________
    Clock       \______/  \_/  \_/  \_/  \_/  \_/  \_/  \_/  \_/  \_/
                ^   ____ ____ ____ ____ ____ ____ ____ ____ ____ ____ ___
    Data    ____|__/    X____X____X____X____X____X____X____X____X____X   \___
                |  Start   0    1    2    3    4    5    6    7    P   Stop
                Request by host

Start bit:  can be long as 300-350us during start up and upto 2500us while key scanning
Request:    Host pulls Clock line down to request to send a command.
Timing:     After Request keyboard pull up Data and down Clock line to low for start bit.
            After request host release Clock line once Data line becomes hi.
            Host wirtes a bit while Clock is hi and Keyboard reads while low.
Stop bit:   Host releases or pulls up Data line to hi after 9th clock and waits for keybaord pull down the line to lo.

Keyboard command
----------------
Keyboard accepts these commands from host.

        Description                             Entry point
    -----------------------------------------------------------
    FF  Soft Reset                              0008h
    FE  Resend                                  00e8h
    FD  Buzzer(emits a short beep)              00edh
    FC  Set Key Flag                            00f6h
    FB  Soft Reset                              0008h
    FA  Reset                                   0000h
*/

  uint8_t bit=0x01; // Ponemos un bit a 1
  uint8_t PARIDAD=1; // Par 0, impar 1
  // Por algún motivo no funciona empezando en 0
  Error=0;
  
  // Comprobamos que estamos en condiciones de enviar datos
  pinMode(DATA,INPUT_PULLUP);
  pinMode(CLK, INPUT_PULLUP);

  Ttotal=micros(); 
  while((digitalRead(CLK)!=HIGH)&(digitalRead(DATA)!=LOW)) {
    // Esperamos a que suba pueden ser 2500 us durante el escaneo
    if(micros()-Ttotal>T_SCAN) {
         Error=5;
         break;
         }
  }
  // Podemos enviar el comando
  Serial.print("Comando: ");
  switch(Comando) {
      case RESET:
          Serial.print("RESET ");
          break;
      case SOFT_RESET:
          Serial.print("SOFT RESET ");
          break;
      case SKF:
          Serial.print("SET KEY FLAG ");
          break;
      case RESEND:
          Serial.print("RESEND ");
          break;
      case BUZZER:
          Serial.print("BUZZER ");
          break;
      default:
          if(Comando&BREAKCODE) Serial.print("BREAK CODE ");
          else Serial.print("ENABLE REPEAT ");
      }
  Serial.print("0x");
  Serial.println(Comando, HEX);
  
  // Empezamos el start bit poniendo CLK a 0 durante 300 usegudos
  habilitaKB();
  clock_lo();

  // Esperamos por el Start bit, KB responda poniendo el DATA en alto
  Ttotal=micros();
  while(digitalRead(DATA)==LOW) {
    //Esperamos a que el teclado responda
    if(micros()-Ttotal>T_SCAN) { // Másimo tiempo es 2500us, por el scan del teclado
         Error=6;
         break;
         }
    }
  // Empieza el Start bit
  // Liberamos el CLK
   pinMode(CLK, INPUT_PULLUP);
   pinMode(DATA,OUTPUT);
   Ttotal=micros();
   while(digitalRead(CLK)==LOW) {
    // Esperamos el reloj para escribir, un ciclo entero 90 us
     if(micros()-Ttotal>T_S_BIT) { // Máximo tiempo es 90us del start bit
         Error=7;
         break;
         }
   }

   
   for(int i=0;i<8;i++) {
            // Escribimos con el CLK arriba, son 60us
            Ttotal=micros();
            if(Comando&bit) {
                digitalWrite(DATA, HIGH);
                PARIDAD++; // Vamos contanto la paridad
                }
            else {
                digitalWrite(DATA, LOW);
                }
            Comando=Comando>>1; // Corremos un bit a la derecha, de LSB a MSB
            while(digitalRead(CLK)==HIGH) {
              //Esperamos que baje el reloj
              if(micros()-Ttotal>T_C_H) { // Máximo 30us
                   Error=8;
                   break;
                   }
            }
            
            //Ciclo reloj abajo 30 us
            // Aquí lee el KB
            while(digitalRead(CLK)==LOW) {
              // Esperamos que suba
              if(micros()-Ttotal>T_CLOCK) { // 60+30=90 más 5 de regalo
                   Error=9;
                   break;
                   }
            }
  }
    //Ponemos paridad
    //Ciclo reloj arriba 60 us
    // Data se escribe en alto
    Ttotal=micros();
    if(PARIDAD&bit) {
        digitalWrite(DATA, HIGH); // suponiendo paridad impar ?
        } 
    else {
         digitalWrite(DATA, LOW);
         }
    while(digitalRead(CLK)==HIGH) {
       // Esperamos
       if(micros()-Ttotal>T_C_H) { // Máximo 60us
           Error=10;
           break;
           }
       }
    //Ciclo reloj abajo 30 us
    // El teclado lee en el ciclo bajo de CLK
    while(digitalRead(CLK)==LOW) {
       // Esperamos
        if(micros()-Ttotal>T_CLOCK) { // Máximo 90us
            Error=11;
            break;
            }
       }

  //Bit de STOP, dejamos el reloj arriba, bit de Stop
  //dejamos el data arriba y eperamos que el teclado lo baje
  digitalWrite(DATA, HIGH);
  // Ponemos como entradas para escuchar
  pinMode(DATA, INPUT_PULLUP);
  while(digitalRead(DATA)==HIGH) {
    // Esperamos que el KB baje el DATA
     if(micros()-Ttotal>(2*T_CLOCK)) { // Contamos dos ciclos de reloj, el de la paridad y el de stop
         Error=12;
         break;
         }
    }
 habilitaKB(); // Habilitamos KB
  

  delayMicroseconds(30);
  // Deberíamos esperar a que el teclado baje el DATA LOW
  //Serial.print(" Paridad: ");
  //if(PARIDAD&0x01) Serial.println("odd"); else Serial.println("even");
  if(Error>0) {Serial.print("\nError de tiempo: "); Serial.println(Error);}
}


// LEER TECLADO
uint8_t LeerTeclado(void) {
/*
Keyboard to Host
----------------
Data bits are LSB first and Pairty is odd. Clock has around 60us high and 30us low part.

            ____       __   __   __   __   __   __   __   __   __   _______
    Clock       \_____/  \_/  \_/  \_/  \_/  \_/  \_/  \_/  \_/  \_/
                 ____ ____ ____ ____ ____ ____ ____ ____ ____ ____
    Data    ____/    X____X____X____X____X____X____X____X____X____X________
                Start   0    1    2    3    4    5    6    7    P  Stop

Start bit:  can be long as 300-350us.
Inhibit:    Pull Data line down to inhibit keyboard to send.
Timing:     Host reads bit while Clock is hi.(rising edge)
Stop bit:   Keyboard pulls down Data line to lo after 9th clock.
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
